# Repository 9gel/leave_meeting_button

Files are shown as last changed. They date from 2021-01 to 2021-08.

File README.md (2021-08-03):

# Zoom Leave Meeting Button
<br/>
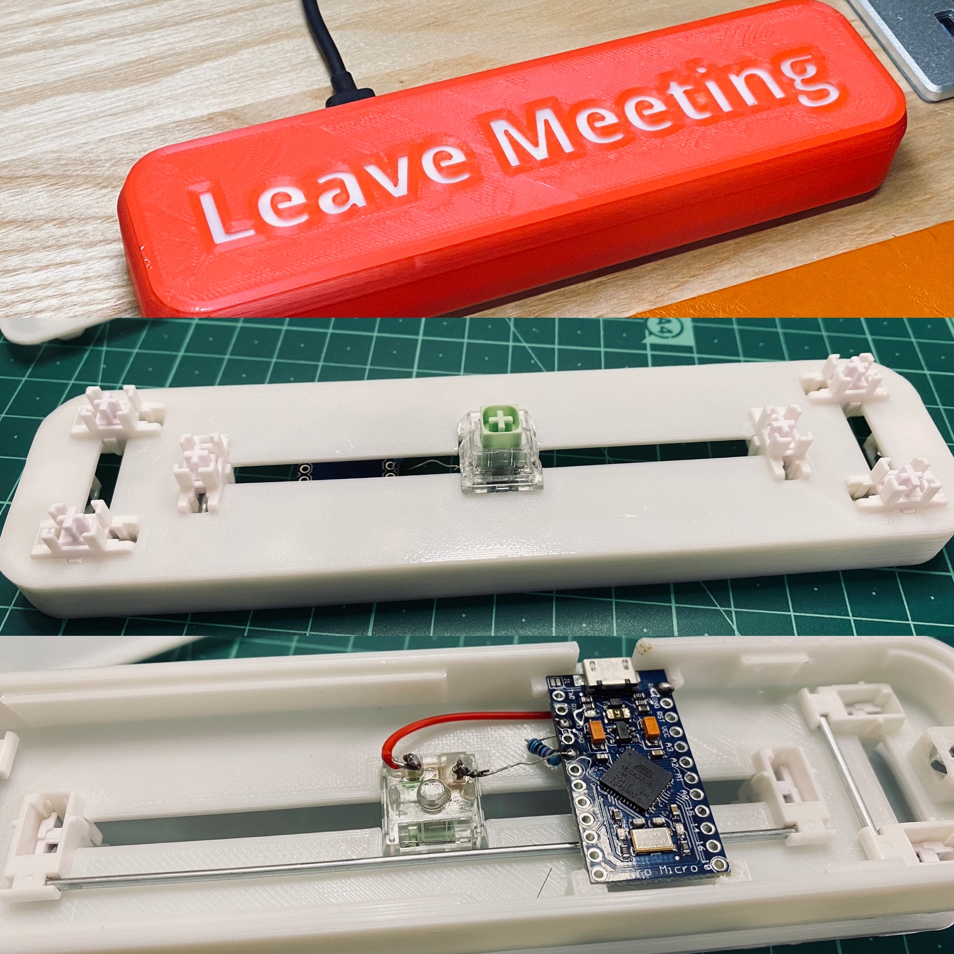
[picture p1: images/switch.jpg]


Files for building your own Single-button "keyboard" that does only one thing - leave any Zoom meetings.

See demo here: https://www.youtube.com/watch?v=0GqqAG8KL6Q
And here's the Reddit thread that prompted the sharing: https://www.reddit.com/r/MechanicalKeyboards/comments/l7to85/singlebutton_keyboard_gives_the_satisfaction_of_a/

## What it is

* A single-switch mechanical keyboard / macropad with a large 3D-printed keycap
* Supported by 3 stabilizers so you can press anywhere on the key
* Powered by a Pro Micro Arduino microcontroller
* Really only sends an Alt-F4 to the active window. So this assumes the Zoom window is the current focus (see improvement ideas below)
* A prototype - not for sale (yet) - if you would rather buy something like this, let me know. If there's enough interest, I'll figure out how to mass-produce this

## How to build (TL;DR)

* Procure:
  * One standard Cherry MX compatible switch - I use [Kailh Jade](https://novelkeys.xyz/products/novelkeys-x-kailh-box-thick-clicks) for the thick click effect. You may consider an even heavier switch, such as the Kailh Navy
  * One 6.25x plate-mounted stabilizer
  * Two 2x plate-mounted stabilizer
  * One Sparkfun Pro Micro, clone, or a microcontroller of your choosing
  * One 10K resistor - 1/4 W worked for me
  * Two M3x10 countersunk screws
  * Two M3 nuts
* Print the 3 STL files
* Wire up the switch and program
  * Flash the Pro Micro - included `leavemeeting` file is an example
  * Wire up the Pro Micro
* Assemble the thing like the above image - more images in the images folder

## Outstanding items

If you can help out here it will be much appreciated:

* Complete the detailed version of the build
* Use [Autohotkey](https://www.autohotkey.com/) for more reliable scripting
* Test on a Mac with different key presses
* Use a cheaper microcontroller - some suggested digispark / Attiny85
* RGB lighting effects?
* Figure out if I should get it mass produced (?)

## How to build (Detailed version)

TODO - circuit diagram, etc.

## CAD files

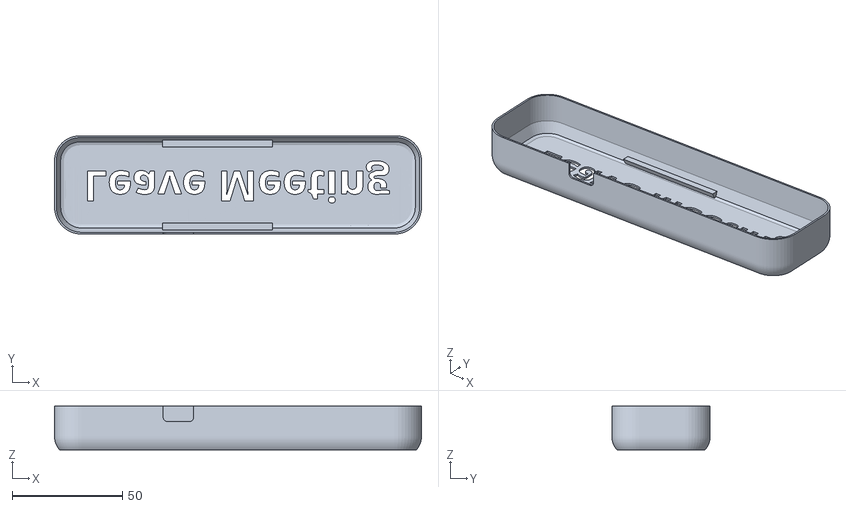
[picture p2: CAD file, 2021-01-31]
stls/Zoom Leave Meeting Device Keycap.stl
166.6 x 44.6 x 19.8

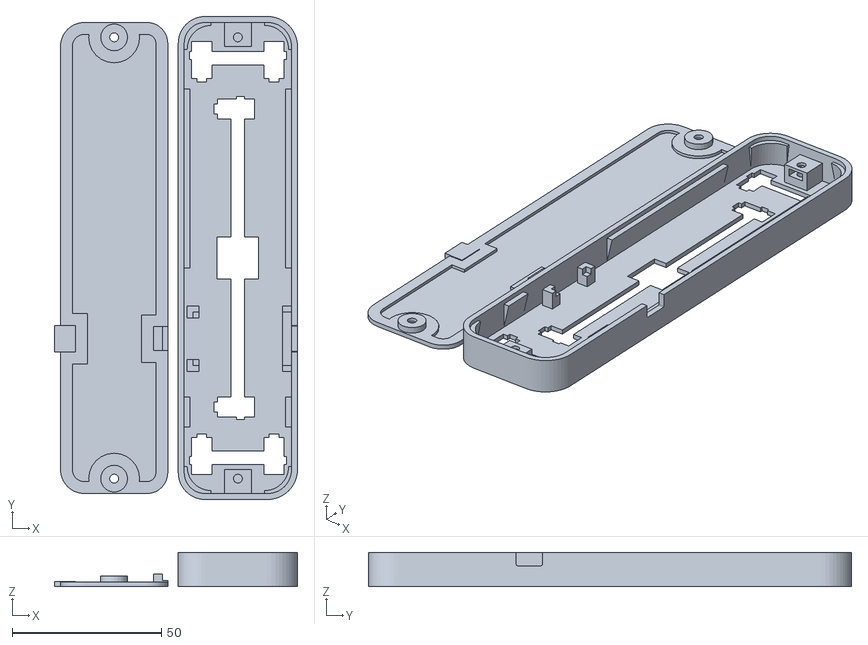
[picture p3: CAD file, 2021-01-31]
stls/Zoom Leave Meeting Device Case.stl
81.5 x 162.0 x 11.5

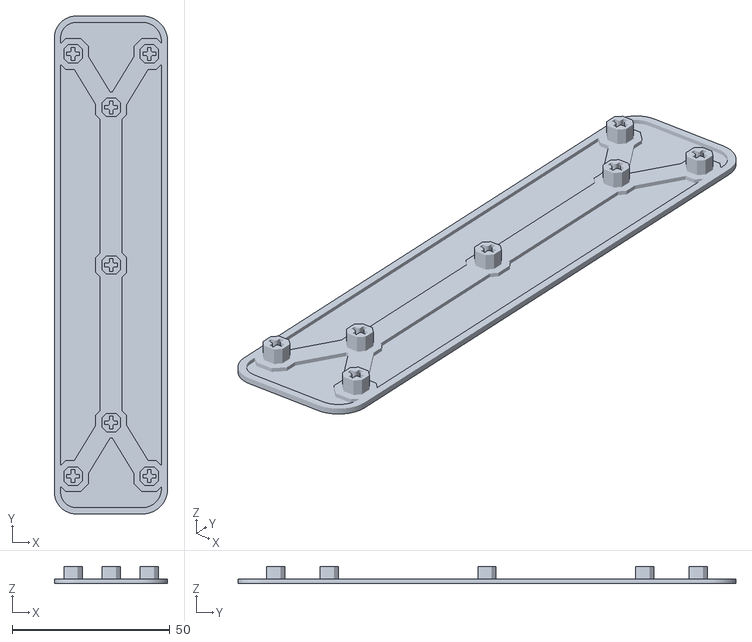
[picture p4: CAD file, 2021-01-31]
stls/Zoom Leave Meeting Device Keycap Base.stl
36.0 x 158.0 x 5.50

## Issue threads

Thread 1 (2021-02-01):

Some Ideas for modifications

aerialviews007, 2021-02-01:
9gel,

Congrats on your design, it's a pretty amazing little device and I'm working on printing one out myself.  I had some thoughts:

QMK software:  QMK has robust support for different key commands and combinations as well as rbg support.  See [this](https://github.com/qmk/qmk_firmware/tree/master/keyboards/bigseries/1key) as an example for a single switch configuration.  It uses the B0 and B4 pins to connect the switch and would not require a resistor.  With QMK, you can have multiple command combinations like one tap to leave zoom, two to leave MS Teams, etc.  Flashing with Via keymap would allow for gui management as well.

Pro Micro is definitely overkill but it's probably the best option since the clones are very inexpensive and easy to find.

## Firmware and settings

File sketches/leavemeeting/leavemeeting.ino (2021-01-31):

#include<Keyboard.h>

const int NUMBUTTONS = 1;
const int MINBUTTON = 2;
const int MAXBUTTON = 21;
const int RXLED = 17;
int pressed[] = {0, 0, 0, 0, 0, 0, 0, 0, 0, 0, 0, 0, 0, 0, 0};

boolean validButton(int i) {
  return i <= MINBUTTON+NUMBUTTONS && i <= MAXBUTTON;
}

void setup() {
  for (int i=MINBUTTON; validButton(i); ++i) {
    pinMode(i, INPUT);
  }
  pinMode(RXLED, OUTPUT);
  Serial.begin(9600);
}

boolean buttonPressed(int pin) {
  if (digitalRead(pin) == HIGH) {
    delay(10);
    if (digitalRead(pin) == HIGH) {
      if (!pressed[pin]) {
        pressed[pin] = 1;
        return true;
      }
    }
  }
  return false;
}

boolean buttonReleased(int pin) {
  if (digitalRead(pin) == LOW) {
    delay(10);
    if (digitalRead(pin) == LOW) {
      if (pressed[pin]) {
        pressed[pin] = 0;
        return true;
      }
    }
  }
  return false;
}

void doPressedAction(int pin) {
  switch(pin) {
    case 2:
    // Uncomment the following if you want to trigger action on press
    Keyboard.press(KEY_LEFT_ALT);
    Keyboard.press(KEY_F4);
    delay(100);
    Keyboard.releaseAll();
    break;
  }
}

void doReleasedAction(int pin) {
  switch(pin) {
    case 2:
    // Uncomment the following if you want to trigger action on release
    //Keyboard.press(KEY_LEFT_ALT);
    //Keyboard.press(KEY_F4);
    //delay(100);
    //Keyboard.releaseAll();
    break;
  }
}

void loop() {
  for (int i=MINBUTTON; validButton(i); ++i) {
    if (buttonPressed(i)) {
      doPressedAction(i);
    }
    if (buttonReleased(i)) {
      doReleasedAction(i);
    }
  }
  digitalWrite(RXLED, HIGH);
}

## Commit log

2021-01-31 First commit of project files
    [Zoom Leave Meeting Device Case.stl, Zoom Leave Meeting Device Keycap Base.stl, Zoom Leave Meeting Device Keycap.stl]
2021-01-31 Updated keycap - lighter, better fit
    [Zoom Leave Meeting Device Keycap.stl]

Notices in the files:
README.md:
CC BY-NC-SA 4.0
